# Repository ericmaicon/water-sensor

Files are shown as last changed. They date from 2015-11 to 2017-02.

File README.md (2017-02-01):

# About it

This is a project for a master degree with the goal of store water flow data in a house.

It uses a flow sensor, connected on an ESP8266 to send it thought the internet to an endpoint.
It has a USBSerial to update the ESP8266 firmware and code.

* [Roadmap](https://github.com/ericmaicon/water-sensor/blob/master/docs/Roadmap.md)

Some research about ESP8266:

* [Espruino firmware](https://github.com/ericmaicon/water-sensor/blob/master/docs/Espruino.md)
* [NodeLUA firmware](https://github.com/ericmaicon/water-sensor/blob/master/docs/Nodelua.md)
* [NodeMCU firmware](https://github.com/ericmaicon/water-sensor/blob/master/docs/Nodemcu.md)
* [AT firmware](https://github.com/ericmaicon/water-sensor/blob/master/docs/AT.md)

Raspberry:

* [Install Debian on Raspberry from Mac](https://github.com/ericmaicon/water-sensor/blob/master/docs/Install-Raspberry.md)
* [Using raspberry and ESP8266 as router](https://github.com/ericmaicon/water-sensor/blob/master/docs/Raspberry.md)

# Useful Links

## Schematics
* [Convert 5V to 3.3V](http://kb.kaminskiengineering.com/node/171)
* [Convert AC to DC](http://www.elprocus.com/steps-to-convert-the-230v-ac-to-5v-dc/)

## Flow Sensor
* [Sensor](http://www.seeedstudio.com/wiki/G1'1/4_Water_Flow_sensor)
* [Datasheet](http://www.seeedstudio.com/depot/datasheet/water%20flow%20sensor%20datasheet.pdf)
* [Datasheet](http://www.hobbytronics.co.uk/datasheets/sensors/YF-S201.pdf)
* [Portuguese Tutorial](http://labdegaragem.com/profiles/blogs/tutorial-como-utilizar-o-sensor-de-fluxo-de-agua)
* [Code example](http://www.hobbytronics.co.uk/download/YF-S201.ino)
* [Tutorial](http://diyhacking.com/arduino-flow-rate-sensor/)
* [Code example](http://diyhacking.com/projects/FlowMeterDIY.ino)

## ESP8266
* [GPIO API](http://esp8266.co.uk/tutorials/introduction-to-the-gpio-api/)
* [Flow Sensor and ESP8266](http://www.esp8266.com/viewtopic.php?f=18&t=5624)
* [Two ESP8266 talking](http://randomnerdtutorials.com/how-to-make-two-esp8266-talk/)
* [Log data in MySQL](https://primalcortex.wordpress.com/2015/02/19/esp8266-logging-data-in-a-mysql-database/)

## Arduino
* [Ethercard](https://github.com/jcw/ethercard)

Arduino drive on MAC:
[Drive](http://www.wch.cn/download/CH341SER_MAC_ZIP.html)
Download, install.

Run:
`sudo nvram boot-args="kext-dev-mode=1"`
reboot

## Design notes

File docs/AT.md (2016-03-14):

# Installing the firmware

Install the driver:
* [Driver](http://www.prolific.com.tw/US/ShowProduct.aspx?p_id=229&pcid=41)

If you have any problems with serial on new mac os versions (el capitain):

[http://scottbrant.net/?p=757](http://scottbrant.net/?p=757)

```
boot mac into recovery mode (command+r). hold it down until you see the mouse cursor
utilities, terminal
csrutil status
probably says enabled
csrutil disable
reboot
```

Download esptool.py:
* [Esptool](https://github.com/themadinventor/esptool)

```
git clone git@github.com:themadinventor/esptool.git
```

Download AT Firmware:
* [AT Firmware](http://www.mediafire.com/download/bn1wpwmc4mcm48c/esp8266+Aplica%C3%A7%C3%A3o+%2B+firmware+%28Vers%C3%A3o+092+e+Lua%29.rar)

connect ESP8266 to USBSerial:
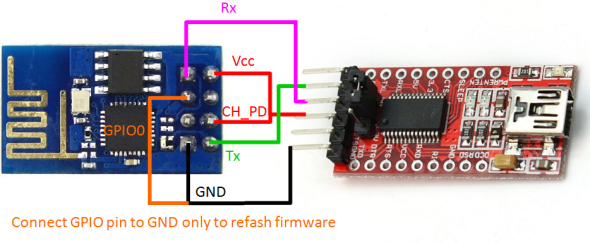
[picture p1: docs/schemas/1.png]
Source: http://iot-playground.com/images/articles/016/esp8266-reflash-firmware.png


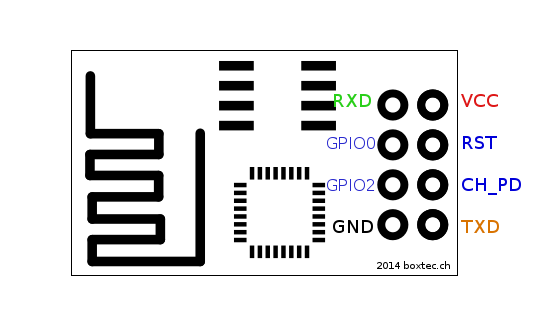
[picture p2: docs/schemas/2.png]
Source: https://raw.githubusercontent.com/guyz/pyesp8266/master/esp8266_pinout.png


Install Python Serial:

```
wget https://bootstrap.pypa.io/get-pip.py
sudo python get-pip.py
sudo pip install pyserial
```

Then, run:
```
./esptool.py --port=/dev/cu.usbserial write_flash  -fm=dio -fs=32m 0x00000 v0.9.2.2\ AT\ Firmware.bin
```

It will return:
> Connecting...
> 
> Erasing flash...
> 
> Wrote 462848 bytes at 0x00000000 in 45.4 seconds (81.6 kbit/s)...
> 
> 
> Leaving...

Disconnect and connect the USB again

# Testing

1. Remove the pin 2 from the ground
2. unplug and plug again the usbserial

Open the Arduino IDE, check if the right usbserial is selected on Serial menu and change the baudrate to 9600.

Open the serial Monitor and type:

```
AT
```

It should return:

> AT
> 
> OK

Try:

```
AT+GMR
```

> AT+GMR
> 
> It should return the firmware serial:
> 0018000902
> 
> OK

# Sequence AT commands used to test with the API

AT+CWLAP
AT+CIFSR

AT+RST
AT+CWMODE=1
AT+CIPMUX=1
AT+CWJAP="",""
AT+CIPSTART=4,"TCP","192.241.153.56",80
AT+CIPSEND=4,178
POST /index.php?r=api/create HTTP/1.1
Host: 192.241.153.56
Content-Type: application/x-www-form-urlencoded
Content-Length: 20

device_id=1&pulse=10

AT+CIPCLOSE

# Useful links
* [https://www.youtube.com/watch?v=Na7CSbq467M](https://www.youtube.com/watch?v=Na7CSbq467M)
* [http://electronut.in/an-iot-project-with-esp8266/](http://electronut.in/an-iot-project-with-esp8266/)
* [http://wiki.iteadstudio.com/ESP8266_Serial_WIFI_Module](http://wiki.iteadstudio.com/ESP8266_Serial_WIFI_Module)
* [http://www.cse.dmu.ac.uk/~sexton/ESP8266/](http://www.cse.dmu.ac.uk/~sexton/ESP8266/)
* [http://mcuoneclipse.com/2014/12/14/tutorial-iot-datalogger-with-esp8266-wifi-module-and-frdm-kl25z/](http://mcuoneclipse.com/2014/12/14/tutorial-iot-datalogger-with-esp8266-wifi-module-and-frdm-kl25z/)
* [http://rootpower.com/?p=73](http://rootpower.com/?p=73)
* [http://contractorwolf.com/esp8266-wifi-arduino-micro/](http://contractorwolf.com/esp8266-wifi-arduino-micro/)
* [https://github.com/contractorwolf/ESP8266](https://github.com/contractorwolf/ESP8266)
* [http://br-arduino.org/2015/05/esp8266-arduino-facil.html](http://br-arduino.org/2015/05/esp8266-arduino-facil.html)
* [https://cdn.sparkfun.com/assets/learn_tutorials/4/0/3/4A-ESP8266__AT_Instruction_Set__EN_v0.30.pdf](https://cdn.sparkfun.com/assets/learn_tutorials/4/0/3/4A-ESP8266__AT_Instruction_Set__EN_v0.30.pdf)
* [http://aura-comms.com/ac/getting-started-with-the-esp8266/](http://aura-comms.com/ac/getting-started-with-the-esp8266/)

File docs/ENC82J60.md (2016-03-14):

# Pin connection
[http://www.dimensaobynet.com.br/mic/wp-content/uploads/2011/12/TabelaPinosConEnc28J60.pdf](http://www.dimensaobynet.com.br/mic/wp-content/uploads/2011/12/TabelaPinosConEnc28J60.pdf)

# Useful links
[http://blog.filipeflop.com/modulos/modulo-ethernet-enc28j60-arduino.html](http://blog.filipeflop.com/modulos/modulo-ethernet-enc28j60-arduino.html)
[http://forum.arduino.cc/index.php?topic=190543.0](http://forum.arduino.cc/index.php?topic=190543.0)
[https://github.com/jcw/ethercard/blob/master/examples/twitter/twitter.ino](https://github.com/jcw/ethercard/blob/master/examples/twitter/twitter.ino)
[https://openenergymonitor.org/emon/node/2309](https://openenergymonitor.org/emon/node/2309)
[http://www.rogerclark.net/aurduino-ethercard-multiple-browser-request-example/](http://www.rogerclark.net/aurduino-ethercard-multiple-browser-request-example/)
[http://jeelabs.org/pub/docs/ethercard/classENC28J60.html](http://jeelabs.org/pub/docs/ethercard/classENC28J60.html)

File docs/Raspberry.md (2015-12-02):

# Connect raspberry with ESP8266

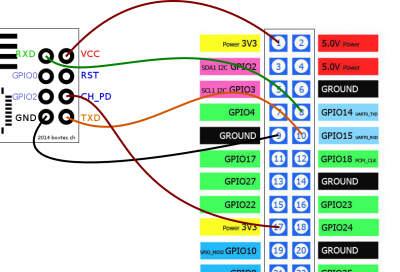
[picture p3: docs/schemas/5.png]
Source: http://www.esp8266.com/wiki/doku.php?id=raspberrypi:getting_started


Connect the raspberry with ESP8266 as the image above.

# Installing the firmware

Install the python serial
```
sudo apt-get install python3-serial python-pip
sudo pip install pyserial
```

Download esptool.py:
* [Esptool](https://github.com/themadinventor/esptool)

```
git clone git@github.com:themadinventor/esptool.git
```

Download NodeMCU:
* [NodeMCU](https://github.com/nodemcu/nodemcu-firmware/releases)

```
wget https://github.com/nodemcu/nodemcu-firmware/releases/download/0.9.6-dev_20150704/nodemcu_integer_0.9.6-dev_20150704.bin
```

connect ESP8266 to USBSerial (Connect the GPI0 to the ground):
Source: http://iot-playground.com/images/articles/016/esp8266-reflash-firmware.png

Source: https://raw.githubusercontent.com/guyz/pyesp8266/master/esp8266_pinout.png

Source: http://www.esp8266.com/wiki/doku.php?id=raspberrypi:getting_started

To avoid problem with the tyAMA0 Serial on Raspberry, it needs to follow the approach below:

```
vim /etc/inittab
``` 

Comment:
> T0:23:respawn:/sbin/getty -L ttyAMA0 115200 vt100)

```
vim /boot/cmdline.txt
```

Remove:

> console=ttyAMA0,115200 kgdboc=ttyAMA0,115200

Reboot raspberry

[https://projects.drogon.net/raspberry-pi/wiringpi/pins/](https://projects.drogon.net/raspberry-pi/wiringpi/pins/)

Then, run:
```
./esptool.py --port=/dev/ttyAMA0 write_flash -fm=dio -fs=32m 0x00000 nodemcu_float_0.9.6-dev_20150704\ 2.bin
```

It will return:
> Connecting...
> 
> Erasing flash...
> 
> Wrote 462848 bytes at 0x00000000 in 45.4 seconds (81.6 kbit/s)...
> 
> 
> Leaving...

Disconnect and connect the USB again

* If the esptool didn't work and return "Failed to connect to ESP8266", try to desconnect and connect the 3.3V from the ESP.

# Send the script to ESP8266

Clone the luatool repository
```
git clone git@github.com:4refr0nt/luatool.git
cd luatool
./luatool/luatool.py --port /dev/ttyAMA0 --src ../water-sensor/raspberry.lua --dest init.lua --verbose
```

It should show at the end:

> --->>> All done <<<---

# Checking the print on Serial:

Install screen:

```
sudo apt-get install screen
```

run it:

```
screen /dev/ttyAMA0 9600
```

# Testing via startx

Open Esplorer:
[Esplorer](http://esp8266.ru/esplorer/)

> java -jar ESPlorer.jar

[http://randomnerdtutorials.com/how-to-make-two-esp8266-talk/](http://randomnerdtutorials.com/how-to-make-two-esp8266-talk/)

# Useful Links

[https://projects.drogon.net/raspberry-pi/wiringpi/pins/](https://projects.drogon.net/raspberry-pi/wiringpi/pins/)

[http://randomnerdtutorials.com/how-to-make-two-esp8266-talk/](http://randomnerdtutorials.com/how-to-make-two-esp8266-talk/)

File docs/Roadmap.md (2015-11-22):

# Roadmap

* Update ESP8266 firmware
* Test the sensor via serial
* Create the circuit
* Develop the system

# The circuit:

* a 5V DC is required
* Converts it to 3.3V with 250mA of current.
* Use 5V on the sensor.
* Use 3.3V on ESP8266
* Use USBSerial
* Create a switch to update or use the GPIO.

# The Circuit System:

* Capture data from the water flow sensor
* Store it
* Check if it has internet, if it has, send it. If it does not have internet, keep trying.

# The WEB System:

* Create an endpoint to receive values
* Check if is receiving data from a sensor, if not, alert.
* Show Charts.
* Show Storage data.

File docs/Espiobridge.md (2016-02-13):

# Installing the firmware

Install the driver:
* [Driver](http://www.prolific.com.tw/US/ShowProduct.aspx?p_id=229&pcid=41)

If you have any problems with serial on new mac os versions (el capitain):

[http://scottbrant.net/?p=757](http://scottbrant.net/?p=757)

```
boot mac into recovery mode (command+r). hold it down until you see the mouse cursor
utilities, terminal
csrutil status
probably says enabled
csrutil disable
reboot
```

Download esptool.py:
* [Esptool](https://github.com/themadinventor/esptool)

```
git clone git@github.com:themadinventor/esptool.git
```

Download esp8266-universal-io-bridge Firmware:
* [esp8266-universal-io-bridge Firmware](https://github.com/eriksl/esp8266-universal-io-bridge/releases/download/11/espiobridge.bin)

connect ESP8266 to USBSerial:
Source: http://iot-playground.com/images/articles/016/esp8266-reflash-firmware.png

Source: https://raw.githubusercontent.com/guyz/pyesp8266/master/esp8266_pinout.png

Install Python Serial:

```
wget https://bootstrap.pypa.io/get-pip.py
sudo python get-pip.py
sudo pip install pyserial
```

Then, run:
```
./esptool.py --port=/dev/cu.usbserial write_flash -fm=dio -fs=32m 0x00000 espiobridge.bin
```

It will return:
> Connecting...
> 
> Erasing flash...
> 
> Wrote 264192 bytes at 0x00000000 in 26.0 seconds (81.1 kbit/s)...
> 
> 
> Leaving...

# Testing

1. Remove the pin 2 from the ground
2. unplug and plug again the usbserial

# Useful links
* [https://github.com/eriksl/esp8266-universal-io-bridge](https://github.com/eriksl/esp8266-universal-io-bridge)
* [http://www.esp8266.com/viewtopic.php?f=6&t=3959&start=76](http://www.esp8266.com/viewtopic.php?f=6&t=3959&start=76)

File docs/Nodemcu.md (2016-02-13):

# Installing the firmware

Install the driver:
* [Driver](http://www.prolific.com.tw/US/ShowProduct.aspx?p_id=229&pcid=41)

If you have any problems with serial on new mac os versions (el capitain):

[http://scottbrant.net/?p=757](http://scottbrant.net/?p=757)

```
boot mac into recovery mode (command+r). hold it down until you see the mouse cursor
utilities, terminal
csrutil status
probably says enabled
csrutil disable
reboot
```

Download esptool.py:
* [Esptool](https://github.com/themadinventor/esptool)

```
git clone git@github.com:themadinventor/esptool.git
```

Download NodeMCU:
* [NodeMCU](https://github.com/nodemcu/nodemcu-firmware/releases)

```
wget https://github.com/nodemcu/nodemcu-firmware/releases/download/0.9.6-dev_20150704/nodemcu_integer_0.9.6-dev_20150704.bin
```

connect ESP8266 to USBSerial:
Source: http://iot-playground.com/images/articles/016/esp8266-reflash-firmware.png

Source: https://raw.githubusercontent.com/guyz/pyesp8266/master/esp8266_pinout.png

Install Python Serial:

```
wget https://bootstrap.pypa.io/get-pip.py
sudo python get-pip.py
sudo pip install pyserial
```

Then, run:
```
./esptool.py --port=/dev/cu.usbserial write_flash  -fm=dio -fs=32m 0x00000 nodemcu_float_0.9.6-dev_20150704.bin
```

It will return:
> Connecting...
> 
> Erasing flash...
> 
> Wrote 462848 bytes at 0x00000000 in 45.4 seconds (81.6 kbit/s)...
> 
> 
> Leaving...

Disconnect and connect the USB again

# Testing
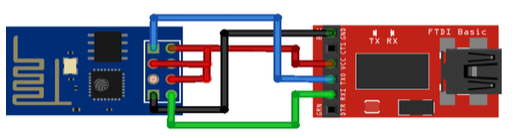
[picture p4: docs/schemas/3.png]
Source: unkonwn


# Send the script to ESP8266

Clone the luatool repository
```
git clone git@github.com:4refr0nt/luatool.git
cd luatool
./luatool/luatool.py --port /dev/ttyAMA0 --src ../water-sensor/raspberry.lua --dest init.lua --verbose
```

Open Esplorer:
[Esplorer](http://esp8266.ru/esplorer/)

Change configs to:
```
port: /dev/cu.usbserial
baudrate 9600
```
Click on Open, it should show:

> PORT OPEN 9600
> 
> Communication with MCU...
> 
> Got answer! AutoDetect firmware...
> 
> 
> Can't autodetect firmware, because proper answer not received.

Use the following script to do a Hello World:
[https://github.com/nodemcu/nodemcu-devkit/wiki/A-Simple-First-Script](https://github.com/nodemcu/nodemcu-devkit/wiki/A-Simple-First-Script)

After put the script on the left side, press "Save to ESP". It will show the script, line by line, on the right side.

# Fast tests

Open CoolTerm and try:
```
gpio.mode(3, gpio.OUTPUT)
gpio.write(3, gpio.UP)
gpio.write(3, gpio.DOWN)
```

# Node GPIO Map
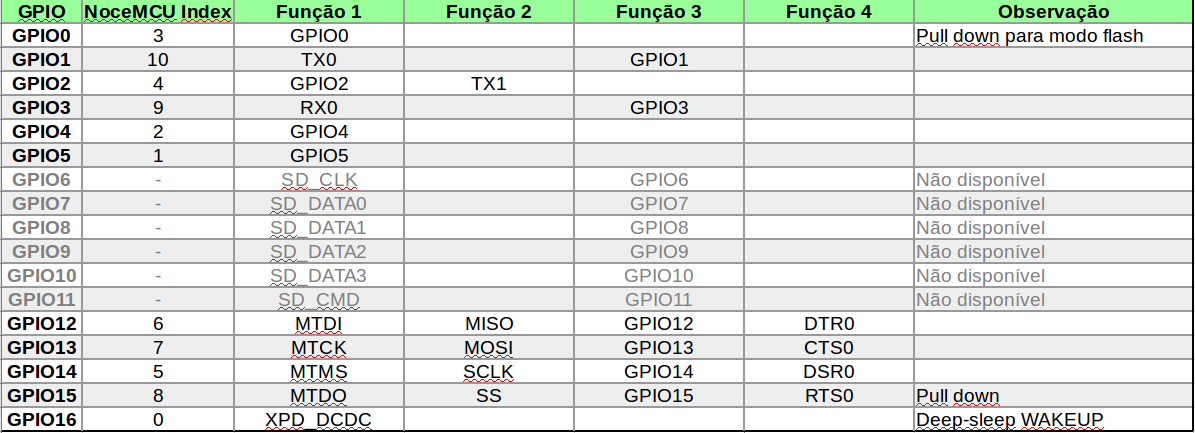
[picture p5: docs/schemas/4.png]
Source: http://pedrominatel.com.br/eletronica/esp8266-o-guia-basico-de-hardware/


# Useful links
* [https://github.com/nodemcu/nodemcu-firmware/wiki/nodemcu_api_en](https://github.com/nodemcu/nodemcu-firmware/wiki/nodemcu_api_en)
* [https://github.com/nodemcu/nodemcu-devkit/wiki/Getting-Started-on-OSX](
https://github.com/nodemcu/nodemcu-devkit/wiki/Getting-Started-on-OSX)

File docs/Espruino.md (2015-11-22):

# Installing the firmware

Download esptool.py:
* [Esptool](https://github.com/themadinventor/esptool)

Download espruino:
* [Espruino](https://github.com/espruino/EspruinoBuilds/tree/master/ESP8266)

connect ESP8266 to USBSerial:
Source: http://iot-playground.com/images/articles/016/esp8266-reflash-firmware.png

Source: https://raw.githubusercontent.com/guyz/pyesp8266/master/esp8266_pinout.png

Then, run:
```
./esptool.py -p /dev/cu.usbserial write_flash 0x00000 EspruinoBuilds-master/ESP8266/espruino_esp8266_board_0x00000.bin 0x010000 EspruinoBuilds-master/ESP8266/espruino_esp8266_board_0x10000.bin
```

It will return:
> Connecting...
> 
> Erasing flash...
> 
> Wrote 62464 bytes at 0x00000000 in 6.1 seconds (81.9 kbit/s)...
> 
> Erasing flash...
> 
> Wrote 371712 bytes at 0x00010000 in 36.6 seconds (81.3 kbit/s)...
> 
> 
> Leaving...

Disconnect and connect the USB again

# Testing
Source: unkonwn

Install the IDE
* [Espruino IDE](https://chrome.google.com/webstore/detail/espruino-web-ide/bleoifhkdalbjfbobjackfdifdneehpo?hl=pt-BR)

Change the baudrate in settings >> communications:
> Baud Rate: 9600

Connect using /dev/cu.usbserial

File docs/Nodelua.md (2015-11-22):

# Installing the firmware

Download esptool.py:
* [Esptool](https://github.com/themadinventor/esptool)

Download nodelua:
* [Nodelua](http://nodelua.org/download_firmware)

connect ESP8266 to USBSerial:
Source: http://iot-playground.com/images/articles/016/esp8266-reflash-firmware.png

Source: https://raw.githubusercontent.com/guyz/pyesp8266/master/esp8266_pinout.png

Then, run:
```
./esptool.py -p /dev/cu.usbserial write_flash 0x00000 nodelua_8266.fw
```

It will return:
> Connecting...
> 
> Erasing flash...
> 
> Wrote 62464 bytes at 0x00000000 in 6.1 seconds (81.9 kbit/s)...
> 
> Erasing flash...
> 
> Wrote 371712 bytes at 0x00010000 in 36.6 seconds (81.3 kbit/s)...
> 
> 
> Leaving...

Disconnect and connect the USB again

# Testing
Source: unkonwn

Install minicom
[Minicom](http://pbxbook.com/other/sw/minicom-2.2.zip)

Configure minicom:
> /opt/minicom/2.2/bin/minicom -s

Connect:
> /opt/minicom/2.2/bin/minicom -D /dev/cu.usbserial -b 115200 -c on

# Useful links
[http://nodelua.org/doc/tutorial/make-your-first-node/](http://nodelua.org/doc/tutorial/make-your-first-node/)

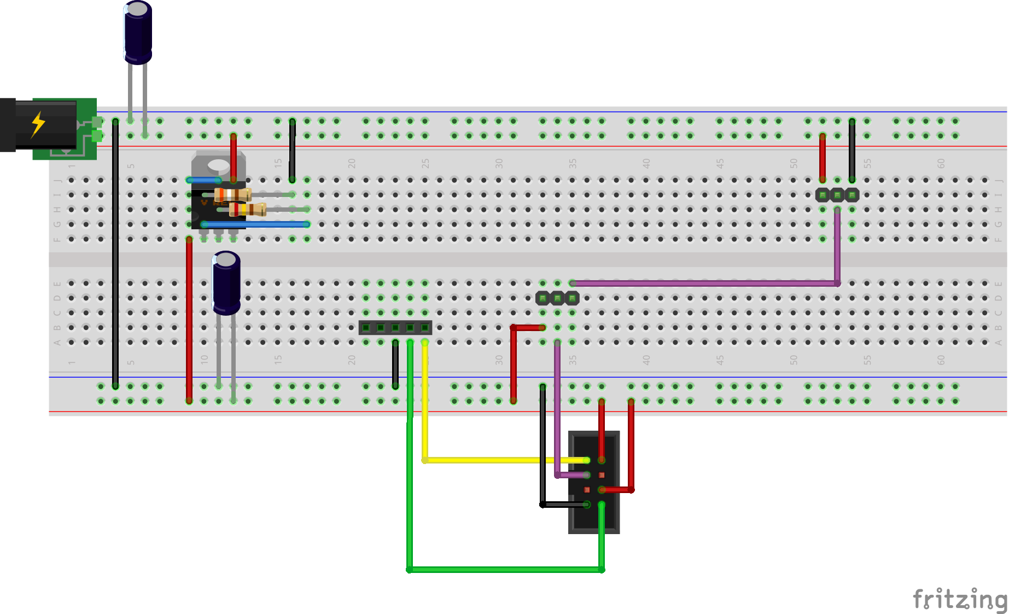
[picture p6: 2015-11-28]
docs/schemas/schematic.png

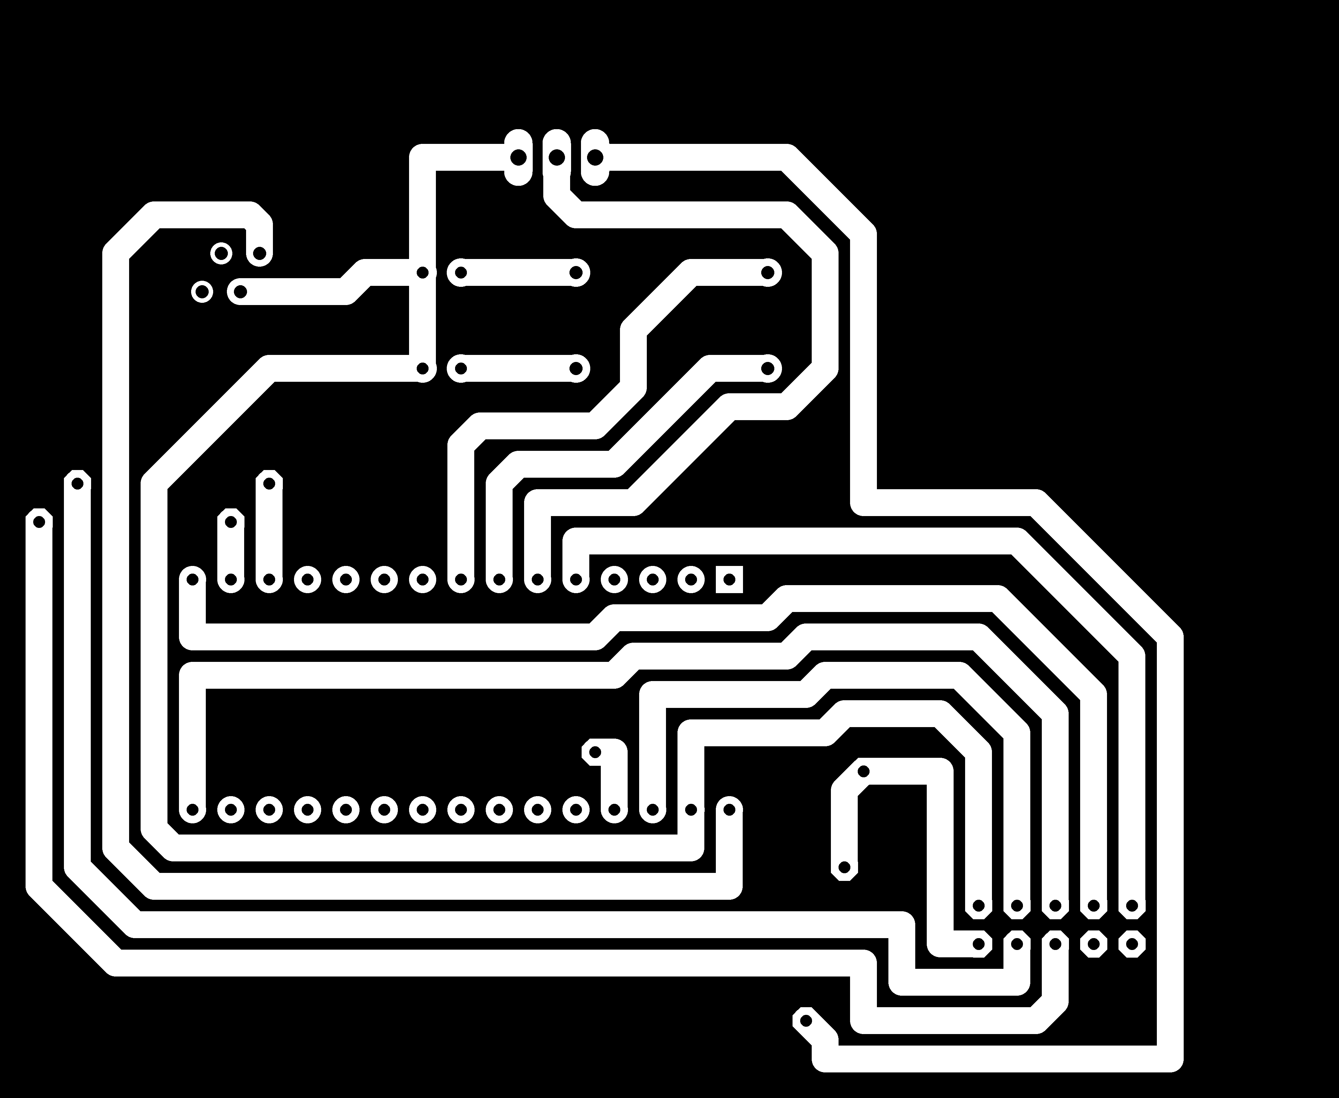
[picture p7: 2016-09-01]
schematic/water-sensor.png

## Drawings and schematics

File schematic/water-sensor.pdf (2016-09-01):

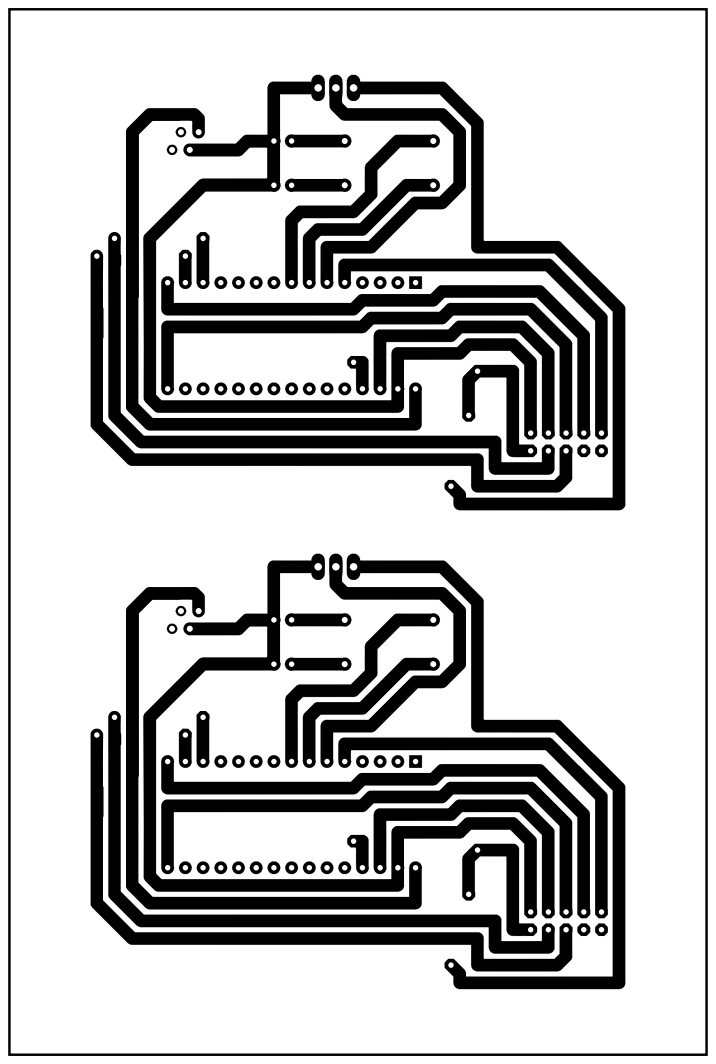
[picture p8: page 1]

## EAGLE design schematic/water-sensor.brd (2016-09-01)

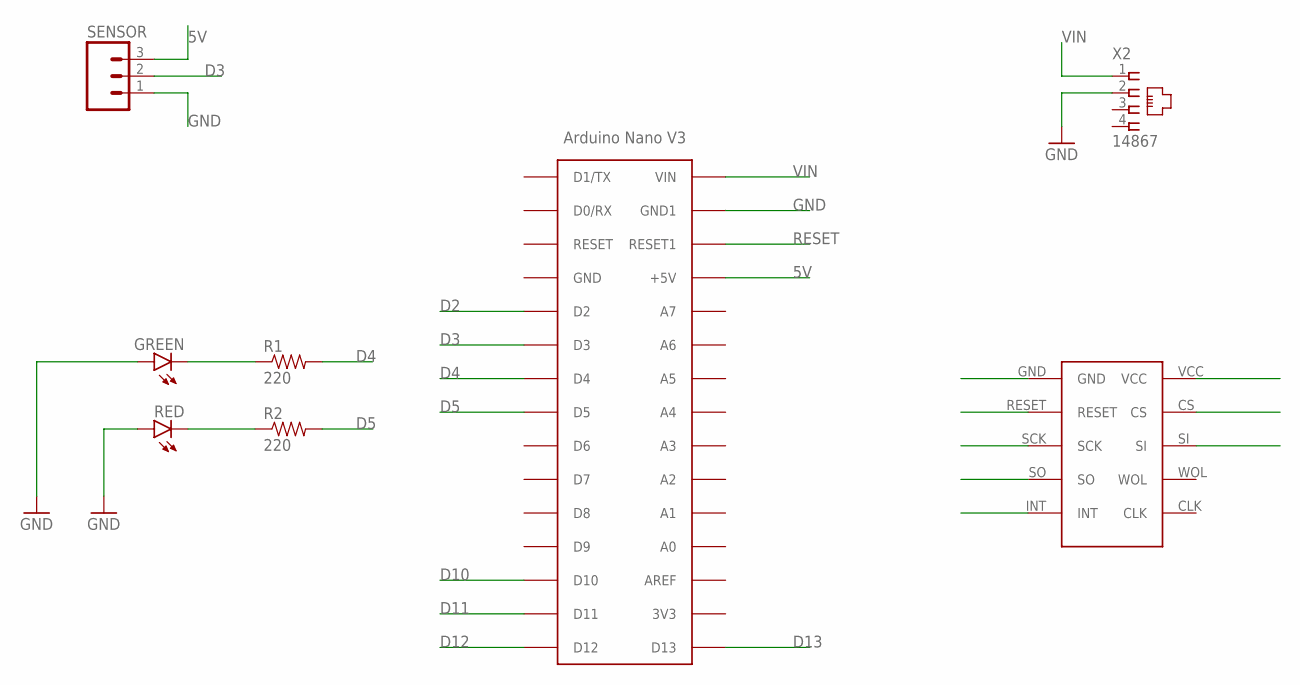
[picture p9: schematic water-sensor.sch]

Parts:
GREEN: LED3MM
R1, R2: 220; AXIAL-0.5
RED: LED3MM
SENSOR: M03LONGPADS; 1X03_LONGPADS
U$1: ARDUINONANO; PDIP-32
U$2: ENC28J60ENC28J60; ENC28J60
X2: 14867

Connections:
5V: SENSOR.3, U$1.+5V, U$2.VCC
D2: U$1.D2, U$2.INT
D3: SENSOR.2, U$1.D3
D4: R1.P$2 (2), U$1.D4
D5: R2.P$2 (2), U$1.D5
D10: U$1.D10, U$2.CS
D11: U$1.D11, U$2.SI
D12: U$1.D12, U$2.SO
D13: U$1.D13, U$2.SCK
GND: GREEN.A, RED.A, SENSOR.1, U$1.GND1, U$2.GND, X2.2
unnamed: GREEN.K (C), R1.P$1 (1)
unnamed: R2.P$1 (1), RED.K (C)
RESET: U$1.RESET1, U$2.RESET
VIN: U$1.VIN, X2.1

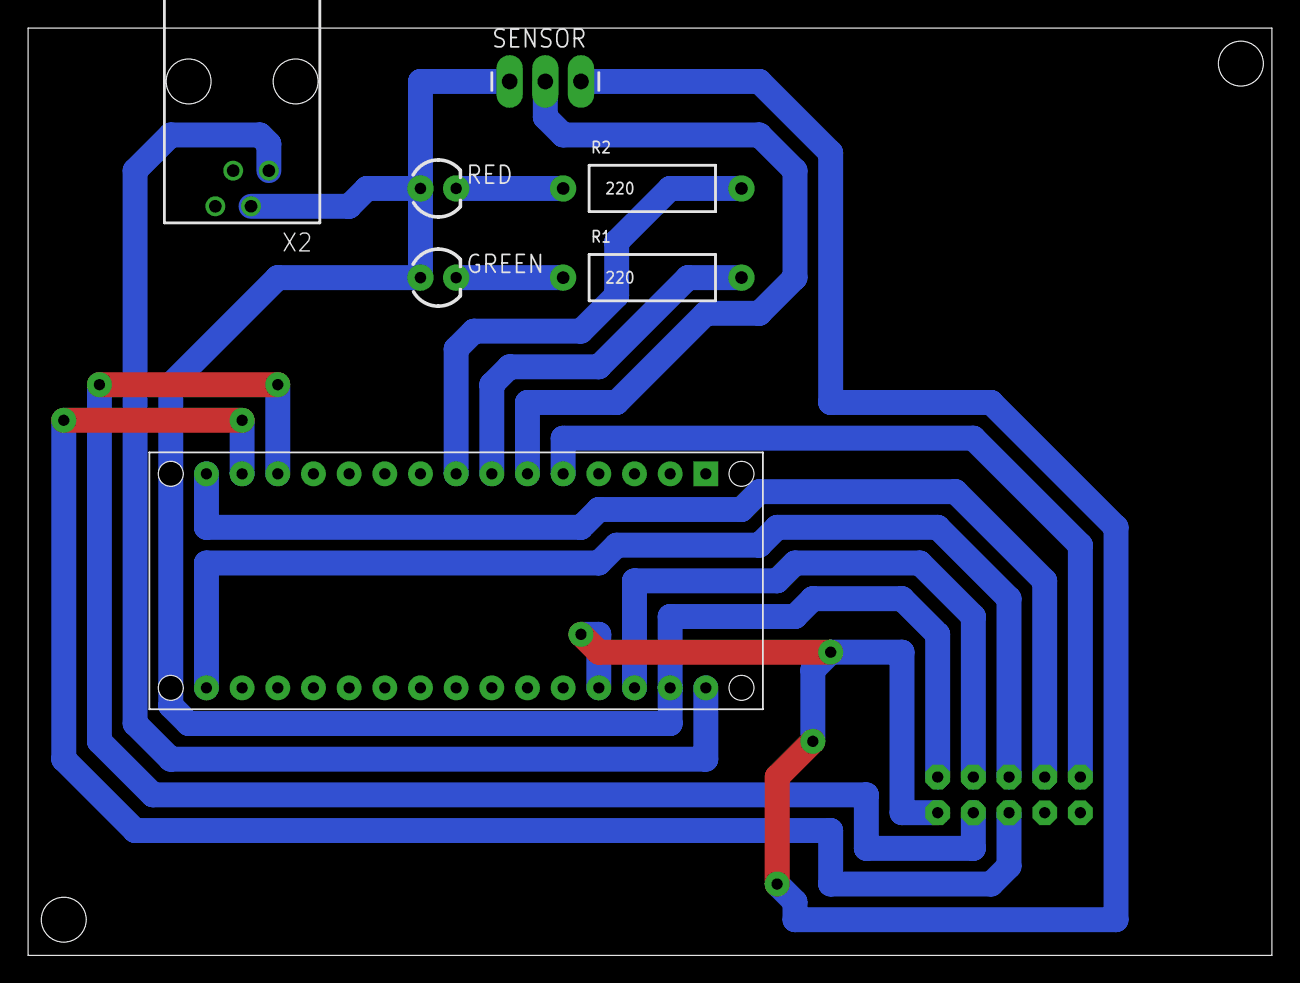
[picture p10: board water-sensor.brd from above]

Board: 2 copper layers, 88.6 x 66.0 mm, 8 parts (1 on the bottom side), 14 nets.

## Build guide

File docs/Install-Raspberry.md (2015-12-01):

# Install Debian on Raspberry from Mac

1. First of all, download [SDFormatter](https://www.sdcard.org/downloads/formatter_4/)
2. Install and format your sdcard.
3. Download [Debian Jessie](https://www.raspberrypi.org/downloads/raspbian/)
4. Download [Pi Filler](http://ivanx.com/raspberrypi/)
5. Run it and install the jessie on your raspberry

# Expand the filesystem

1. After finish, put it on raspberry and start the SO.
2. Get logged in with user pi and password raspberry.
3. run the command:
```
raspi-config
```
4. Select the first option and reboot the system.
5. Run df -h and check the size of the filesystem.

# WIFI on Raspberry

```
vim /etc/network/interfaces
```

> auto wlan0
> allow-hotplug wlan0
> iface wlan0 inet dhcp
> wpa-ssid "WIFI_NAME"
> wpa-psk "WIFI_PASS"

```
ifdown wlan0
ifup wlan1
```

# Install node

```
curl -sLS https://apt.adafruit.com/add | sudo bash
sudo apt-get install node
node -v
v0.12.0
```

# How to keep the process always up

1. Create a receive.service file on /etc/systemd/system/ (or move it)
2. Activate the service:
```
systemctl enable receive.service
```
3. Start it:
```
systemctl daemon-reload
systemctl start receive.service
```

# Crontab

```
crontab -e
```

*/5 * * * * /home/pi/water-sensor/js/sync/sync.sh

# Useful Links

[http://elinux.org/RPi_raspi-config#The_raspi-config_script](http://elinux.org/RPi_raspi-config#The_raspi-config_script)
[https://learn.adafruit.com/node-embedded-development/installing-node-dot-js](https://learn.adafruit.com/node-embedded-development/installing-node-dot-js)
[http://forums.debian.net/viewtopic.php?f=5&t=122427](http://forums.debian.net/viewtopic.php?f=5&t=122427)

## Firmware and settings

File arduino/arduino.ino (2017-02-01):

#include <EtherCard.h>

byte sensorInterrupt = 1;
byte sensorPin = 3;
byte redLedPin = 4;
byte greenLedPin = 5;

//CHANGE
String deviceId = "23";
uint8_t mac[6] = {0x00,0x01,0x02,0x23,0x23,0x23};
const static uint8_t ip[] = {192,168,1,123};
String token = "270590391d1e9dc96c77ab762d287007";
//CHANGE

//LAN
const static uint8_t gw[] = {192,168,1,1};
const static uint8_t dns[] = {192,168,1,1};
const char website[] PROGMEM = "ruanydepaula.com.br";
byte Ethernet::buffer[700];
static byte session;
Stash stash;
//LAN

volatile byte pulseCount;  
float pulse;
float pulseTotal;
unsigned long oldTime;

void setup()
{
    Serial.begin(9600);

    pinMode(sensorPin, INPUT_PULLUP);
    pinMode(redLedPin, OUTPUT);
    pinMode(greenLedPin, OUTPUT);
    attachInterrupt(sensorInterrupt, pulseCounter, FALLING);

    pulseTotal = 0;
    networkStart();
}

void pulseCounter ()
{
    pulseCount++;
}

void networkStart ()
{
    bool isOk = true;
    
    setLed(redLedPin, HIGH);
    setLed(greenLedPin, HIGH);
    Serial.println("Starting ethernet...");
    if (ether.begin(sizeof Ethernet::buffer, mac, 10) == 0) {
        Serial.println(F("Failed to access Ethernet controller"));
        isOk = false;
    }
    
    if (!ether.staticSetup(ip, gw, dns)) {
        Serial.println(F("Static IP failed"));
        isOk = false;
    }

    if (!ether.dnsLookup(website)) {
        Serial.println(F("DNS failed"));
        isOk = false;
    }

    ether.printIp("IP:  ", ether.myip);
    ether.printIp("SRV: ", ether.hisip);

    if (isOk) {
        setLed(redLedPin, LOW);
        setLed(greenLedPin, HIGH);
    }
}

void loop()
{
    receiveAnswer();

    if ((millis() - oldTime) > 1000) { 
        detachInterrupt(sensorInterrupt);

        pulse = ((1000.0 / (millis() - oldTime)) * pulseCount);
        Serial.println("Pulse: " + String(pulse));

        if (pulse != 0) {
            sendToServer(pulse);
            pulseTotal += pulse;
        }

        if (pulse == 0 && pulseTotal != 0) {
            Serial.println("Pulse Amount: " + String(pulseTotal));
            pulseTotal = 0;
            setLed(redLedPin, LOW);
            setLed(greenLedPin, HIGH);
        }

        oldTime = millis();
        pulseCount = 0;

        attachInterrupt(sensorInterrupt, pulseCounter, FALLING);
    }
}

void receiveAnswer ()
{
    ether.packetLoop(ether.packetReceive());
  
    const char* reply = ether.tcpReply(session);
    if (reply != 0) {
        Serial.println("Answer Received");
    }
}

void sendToServer (float pulseAmount)
{
    setLed(redLedPin, HIGH);
    setLed(greenLedPin, HIGH);

    String params = "device_id=" + deviceId + "&pulse=" + String(pulseAmount) + "&time=1&token=" + token;
    Serial.println("Sending: " + params + " Size: " + String(params.length()));

    byte sd = stash.create();
    stash.print(params);
    stash.save();
    int stashSize = stash.size();

    Stash::prepare(PSTR("POST http://$F/index.php?r=api/create HTTP/1.1" "\r\n"
"Host: $F \r\n"
"Content-Length: $D" "\r\n"
"Content-Type: application/x-www-form-urlencoded \r\n"
"\r\n"
"$H"), website, website, stashSize, sd);

    session = ether.tcpSend();
    if (stash.freeCount() <= 3) {
        Stash::initMap(56);
    }
}

void setLed (byte led, int statusLed)
{
    digitalWrite(led, statusLed);
}

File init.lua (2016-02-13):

--===VAR===--
--GPIO Pin
--3 = GPIO 0
pin = 3
pulse = 0
flow = 0
flowAmount = 0
flowTime = tmr.time()
startTime = tmr.time()

serverIp = "192.168.4.1"
deviceId = 1

--===FUNCTIONS===--
--Function to count pulse
function pulseUp(level)
    pulse = pulse + 1  
end


--===WIFI===--
--starting the wifi and connect to the server
function wifiConnect()
    wifi.sta.disconnect()
    wifi.setmode(wifi.STATION) 
    wifi.sta.config("WIFI_FLOW_SENSOR","wMm2XKBgdYdeH2G2vGwM")
    wifi.sta.connect() 
    print("Connecting...")

    tmr.alarm(0, 2000, 1, function()
        if(wifi.sta.getip() ~= nil) then
            tmr.stop(0)
            print("Connected!")
            print("Client IP Address:", wifi.sta.getip())
          else
             print("Connecting...")
          end
    end)
end

--send data to the server
function sendData (localFlowTime, localFlowAmount, localDeviceId)
    if(wifi.sta.getip() ~= nil) then
        print("Sending...")
        cl=net.createConnection(net.TCP, false)
        cl:connect(80, serverIp)
        cl:send(localFlowTime .. ";" .. localFlowAmount .. ";" .. localDeviceId) 
    else
        print("Connection Lost. Connecting again")
        wifiConnect()
    end
end

--===INIT===---
--===FLOW SENSOR===---
--set ping as interrupt
gpio.mode(pin, gpio.INT, gpio.PULLUP)

--set the function callback
gpio.trig(pin, "up", pulseUp)

--id, 1s, 1xrepeat, callback
tmr.alarm(1, 1000, 1, function()
    flow=pulse/5.5

    if (flow~=0) then
        if (flowAmount ~= 0) then
            flowTime = tmr.time()
        end

        flowAmount = flowAmount + flow
    end

    if (flow == 0 and flowAmount ~= 0) then
        print("Sending: time=" .. flowTime .. "&flow=" .. flowAmount .. "&device_id=" .. deviceId)
        sendData(flowTime, flowAmount, deviceId)
        flowAmount = 0
        flowTime = 0
    end

    sendData(10, 10, deviceId)
    print("\nTime from start: " .. tmr.time()-startTime)
    print("l/m: " .. flow)

    --reset the pulse
    pulse = 0
end )

--This line is set to avoid hardware problem
--More: http://www.esp8266.com/viewtopic.php?f=18&t=5624
pwm.setup(2,50,512)
pwm.start(2)

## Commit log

2015-11-22 doing the first hello world with the sensor. Create the structure on raspberry to received infos from others esp8266
2015-11-22 raspberry hello world
2015-11-28 js part to receive records and sync with mysql DO done
    [schematic.fzz]
2015-11-30 raspberry doc and prepare js script
2015-12-01 change raspberry esp code
2015-12-02 fixing the init.lua and the raspberry one
    [init.lua]
2015-12-10 update the PCB
    [schematic.fzz]
2016-01-31 change the project scope to use arduino together with ESP8266
2016-02-14 arduino code
2016-02-21 enc28j60 schematic
    [enc28j60.fzz]
2016-02-28 new schematic with enc28j60
    [enc28j60.fzz]
2016-03-12 arduino schema update
    [enc28j60.fzz]
2016-03-12 power schema
    [enc28j60.fzz, power.fzz]
2016-03-14 final code from arduino running the water sensor
    [schematic.fzz]
2016-03-21 sensor schematic
    [power.fzz, schematic.fzz, water-sensor.brd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]
2016-03-21 water sensor
    [water-sensor.brd, water-sensor.sch]
2016-11-04 little changes on arduino.ino
2017-02-01 arduino changes

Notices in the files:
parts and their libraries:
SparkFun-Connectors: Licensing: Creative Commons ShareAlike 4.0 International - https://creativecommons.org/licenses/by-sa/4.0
